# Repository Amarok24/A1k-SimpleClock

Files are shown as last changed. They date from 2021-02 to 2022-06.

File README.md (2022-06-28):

A1k SimpleClock
===============  

This is an easy to build D.I.Y. Realtime Clock (RTC) for Amiga 500 and Amiga 1000 Computers, which\
will fit under the 68k CPU or any turboboard for 68k sockets.\
\
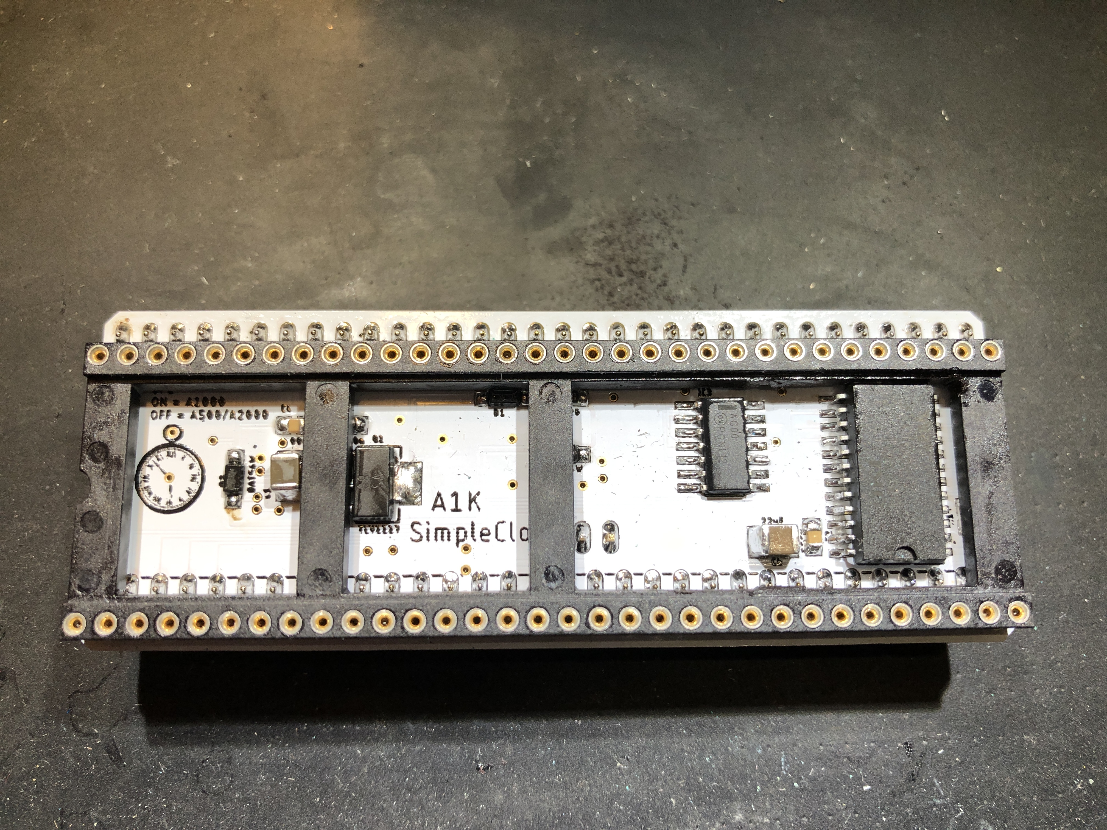
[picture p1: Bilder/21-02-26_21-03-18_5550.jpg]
\
\
For use in Amiga1000 and Kick1.3 you need a patched setclock binary.\
For use in Amiga1000 and Kick >= 2.0 you need a patched battclock_resource modul.\
All these needed files are in (A1kSimpleClock.lha)
\
\
1 * MSM62X42BGS (Clockchip),\
alternative you can use an Epson RTC-72423A instead (pincompatible and in Digikey BOM)\
\
1 * MS920SE (3V Lithium Accu Cell)\
\
These both are available at Mouser or Aliexpress, the Epson Chip is available at Digikey,too.\
\
JP1\
ON = Amiga1000\
OFF = Amiga500/2000\
\
IMPORTEND,\
IC3 needs to be an AC/ACT Type, slower types like HC or HCT won't work!\
\
**Diode orientation**\
\
D1 = Kathode on the right -->|--\
D2 = Kathode on the left --|<--\
D3 = Kathode down\
ah, btw. every SOD123 Schottky Diode with uf<=0.3V will work\
\
**DISCLAIMER!!!!**\
**THIS IS A HOBBYIST PROJECT! I'M NOT RESPONSIBLE IF IT DOESN'T WORK OR DESTROYS YOUR VALUABLE DATA OR HARDWARE!**\
\
https://mytube.madzel.de/videos/watch/4dbfa021-77f8-47c4-a0fa-2a3ab73ecad1 \
\
You can find more information at:\
https://www.a1k.org/forum/index.php?threads/77371/ 
\
\
Original Source is: https://gitlab.com/marceljaehne/a1k-simpleclock/

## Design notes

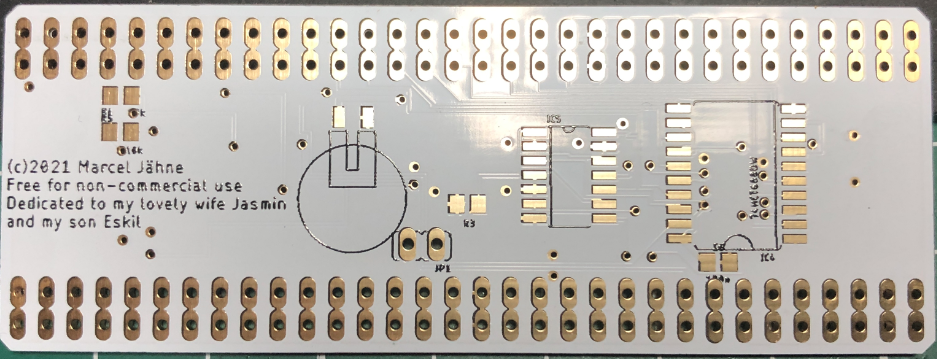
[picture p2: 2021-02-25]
Bilder/A1KSimpleClockFinal_back.PNG

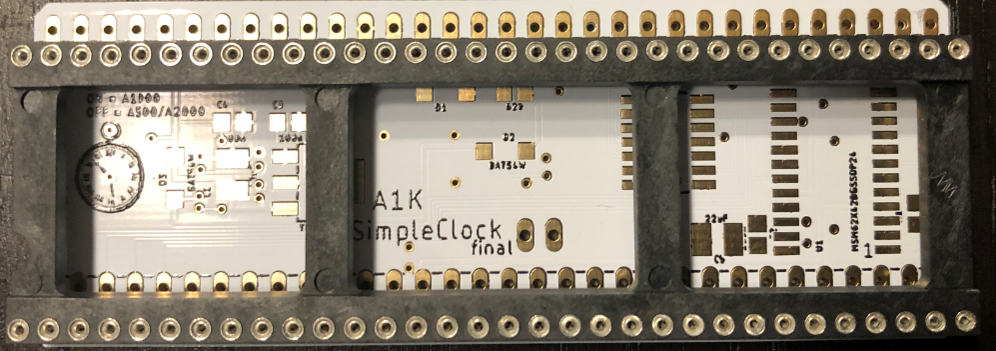
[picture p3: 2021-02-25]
Bilder/CPU_Place_down_row.PNG

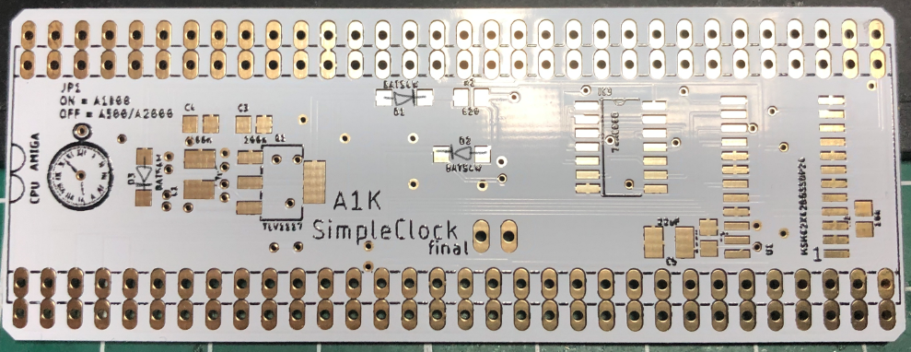
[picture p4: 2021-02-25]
Bilder/A1KSimpleClockFinal_front.PNG

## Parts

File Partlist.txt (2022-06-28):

Partlist

Exported from A1000RTC.brd at 19.12.20 19:40

EAGLE Version 9.6.2 Copyright (c) 1988-2020 Autodesk, Inc.

Assembly variant: 

Part     Value            Package       Library       Position (mil)        Orientation

BATT     MS920SE          BATTCON_9.5MM Amiga Matze   (2300 1690)           MR90
C1       47uF             C1210         rcl           (990 1750)            R90
C2       100n             C0805         rcl           (2710 1540)           R270
C3       100n             C0805         rcl           (1182 1930)           R0
C4       100n             C0805         rcl           (990 1932)            R0
C5       22uF             C1210         rcl           (2462 1536)           R180
C6       100n             C0805         rcl           (1036 1470)           MR0
D1       BAT54W           SOD123        diode         (1730 2028)           R180 (or any other Schottky diode with uf<=0.3v)
D2       BAT54W           SOD123        diode         (1940 1820)           R0  (or any other Schottky diode with uf<=0.3v)
D3       BAT54W           SOD123        diode         (790 1740)            R90 (or any other Schottky diode with uf<=0.3v)
IC1                       DIL64         micro-mc68000 (1900 1700)           R0
IC2                       DIL64         micro-mc68000 (1900 1810)           R0
IC3      74AC00D          SO14          74xx-eu       (2514 1864)           R270
IC4      74HCT688DW       SO20W         74xx-eu       (970 1776)            MR90
IC5      74HCT86D         SO14          74xx-eu       (1546 1768)           MR270
JP1                       JP1           jumper        (1888 1534)           MR90
Q1       TLV1117          SOT223-4      ti-parts      (1290 1720)           R270
R1       10k              R0805         rcl           (3352 1590)           R90
R2       330              R0805         rcl           (1974.59843 2028)     R0
R3       10k              R0805         rcl           (1900 1666)           MR180
R4       10k              R0805         rcl           (3058 2042)           MR0
R5       10k              R0805         rcl           (3058 1912)           MR0
U1       MSM62X42BGSSOP24 SOP24         OKI MSM6242B  (3048 1782)           R90

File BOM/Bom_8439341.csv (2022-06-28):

Hersteller-Teilenummer | Digi-Key Teilenummer | Menge
TLV1117-33IDCYR | 296-21113-1-ND | 1
EMK325BJ476MM-P | 587-5436-1-ND | 1
CL32A226MOJNNNE | 1276-1851-1-ND | 1
885012207045 | 732-8045-1-ND | 4
RNCP0805FTD10K0 | RNCP0805FTD10K0CT-ND | 5
CRG0805F620R | A126381CT-ND | 1
NRVB120VLSFT1G | NRVB120VLSFT1GOSCT-ND | 3
110-99-964-41-001000 | ED3764-ND | 1
RTC-72423A: ROHS | SER3241-ND | 1
SN74ACT00DR | 296-14690-1-ND | 1
SN74AHCT86DR | 296-4776-1-ND | 1
CD74HCT688M96 | 296-24357-1-ND | 1
920-0172-01 | 1988-1163-ND | 2

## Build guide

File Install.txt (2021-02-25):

Amiga 500/2000
 - JP1 OPEN
 - nothing to install (simple, eh? :D)

Extract A1kSimpleClock.lha

Amiga 1000 
(Workbench1.3)

JP1 = CLOSED
 - Copy setclock from A1kSimpleClock.lha to Sys:C and replace original setclock
 - Restart Amiga 

Amiga 1000
(Workbench 3.x)

JP1 = CLOSED
 - Copy battclock.resource from A1kSimpleClock.lha to Sys:libs/resources/
 - Copy LoadModule to Sys:C
    -> You can get it here: https://aminet.net/package/util/boot/LoadModule
 - Edit S:startup-sequence and insert as first line
C:LoadModule LIBS:resources/battclock.resource DOWNGRADE
 - Save S:startup-sequence
 - Restart Amiga

After first startup the A1kSimpleClock, it might be necessary to reset the clock.
Type in CLI: setclock reset
